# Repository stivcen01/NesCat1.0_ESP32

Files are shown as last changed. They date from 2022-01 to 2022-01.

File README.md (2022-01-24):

# NesCat1.0_ESP32
Due to increased popularity of NesCat 0.5 project, I remastered old version of NESCAT 1.0 (NCAT) project (this is deprecated version).
This is experimental version and nothing is guaranteed.



SCHEMATIC:

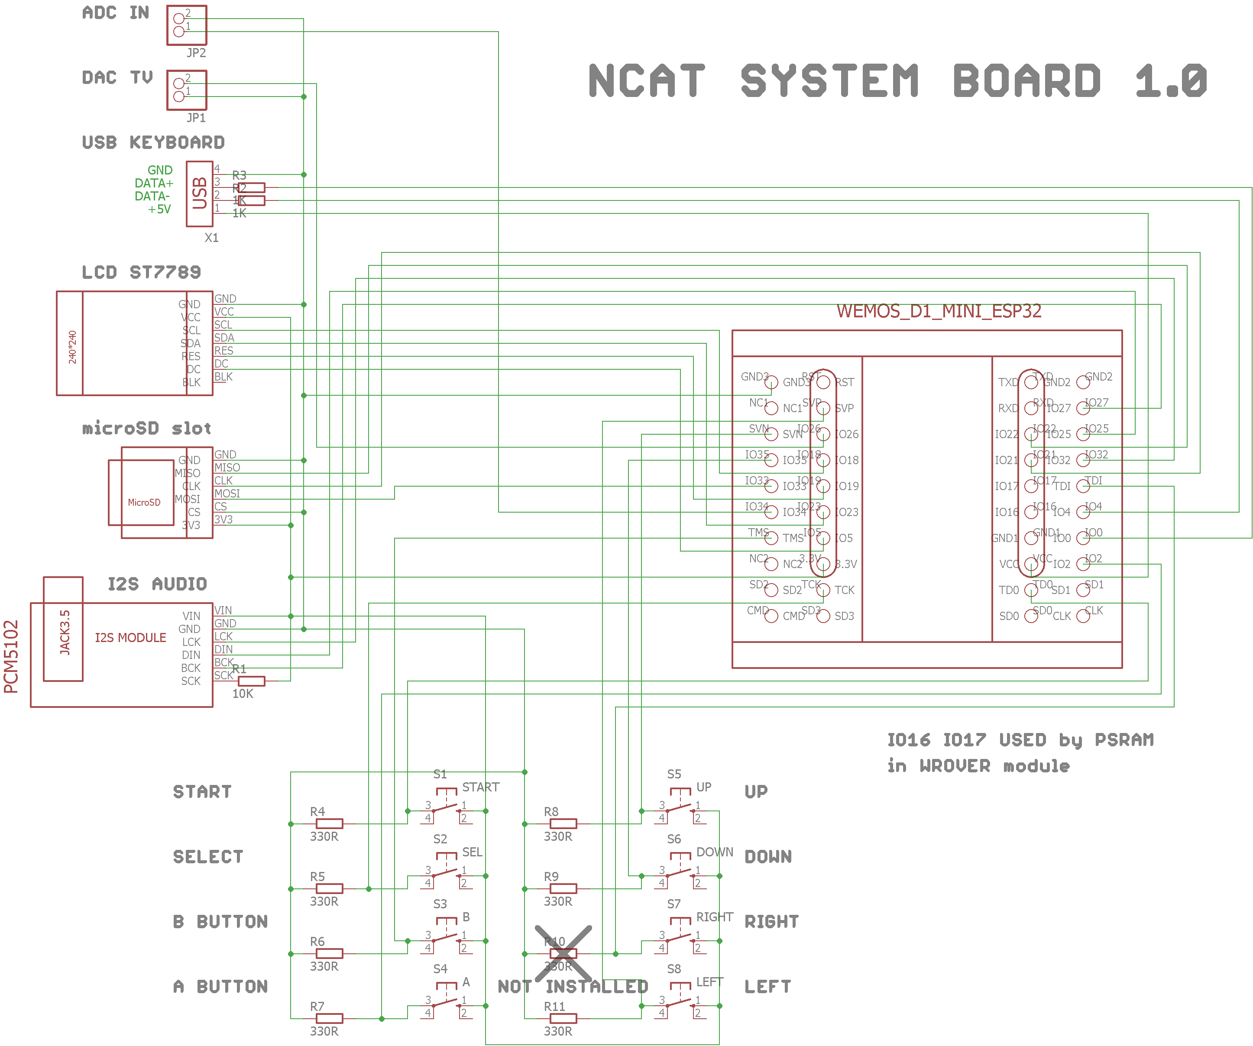
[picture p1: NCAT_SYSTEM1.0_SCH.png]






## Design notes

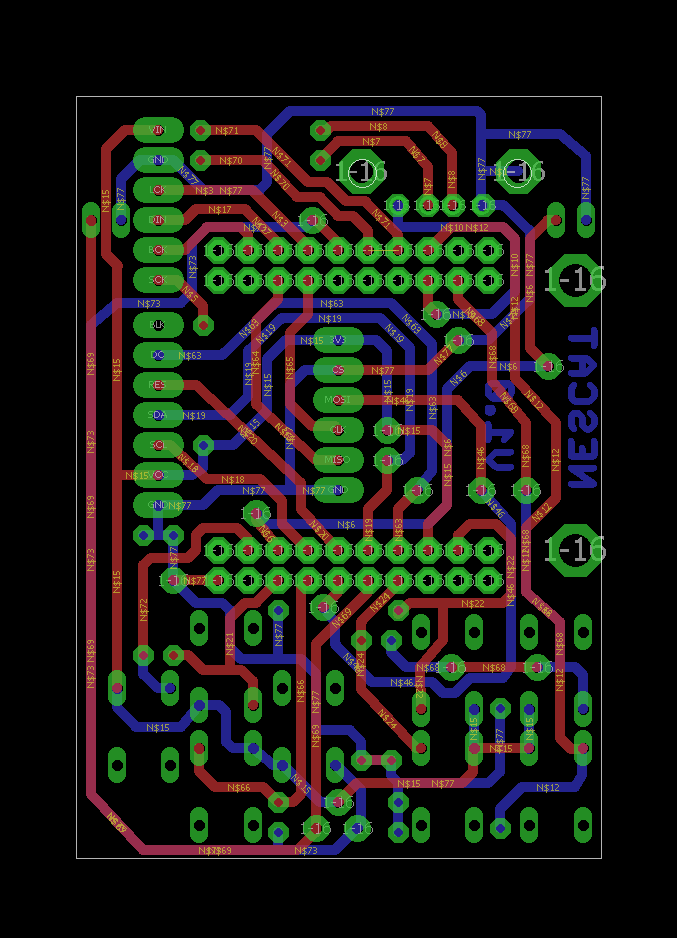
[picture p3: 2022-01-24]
HARDWARE/PCB NESCAT 1.0/NESCAT1.0_BRD2.png

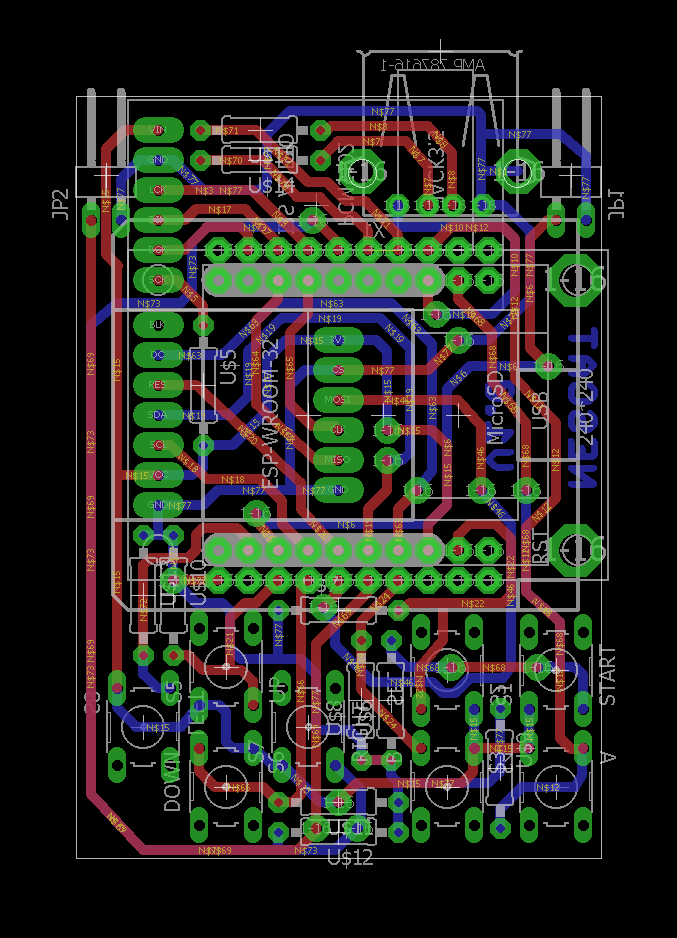
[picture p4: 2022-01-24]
HARDWARE/PCB NESCAT 1.0/NESCAT1.0_BRD.png

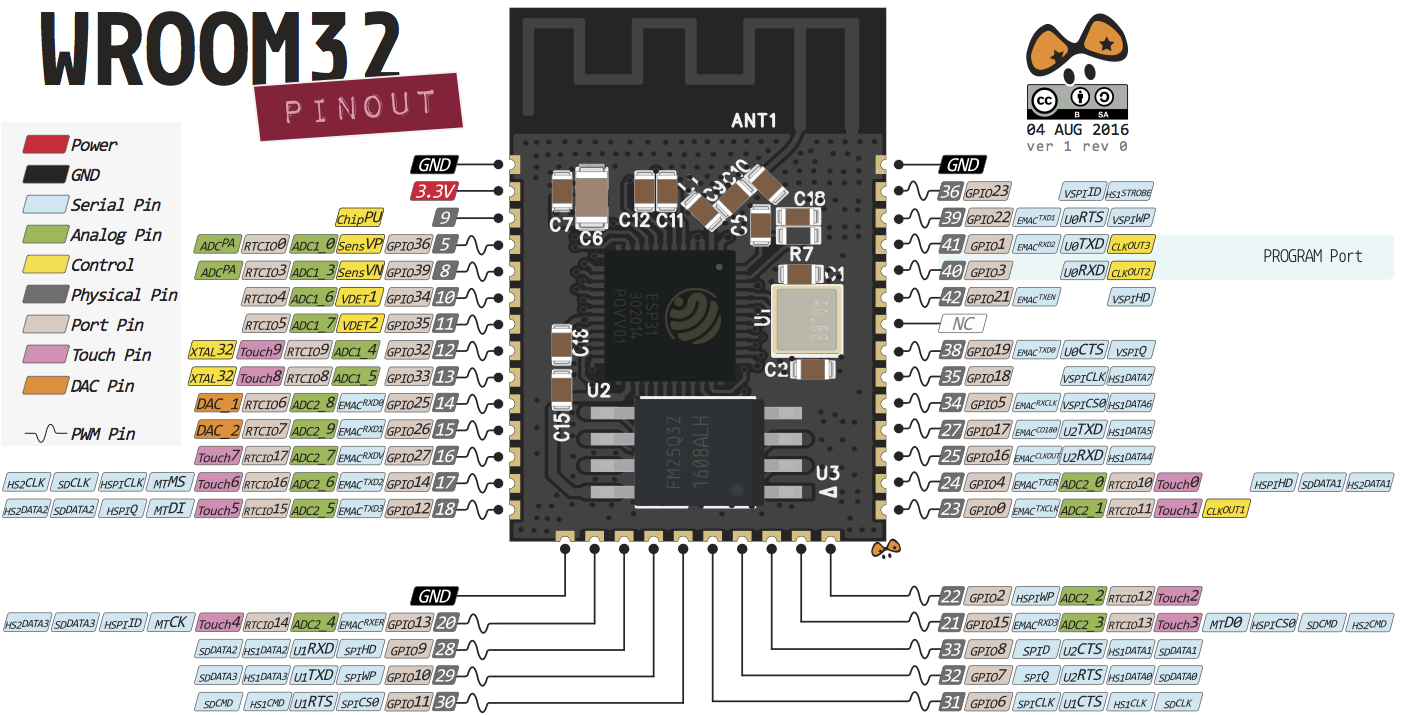
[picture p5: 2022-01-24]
RESOURCES/esp32-pinout-chip-ESP-WROOM-32.png

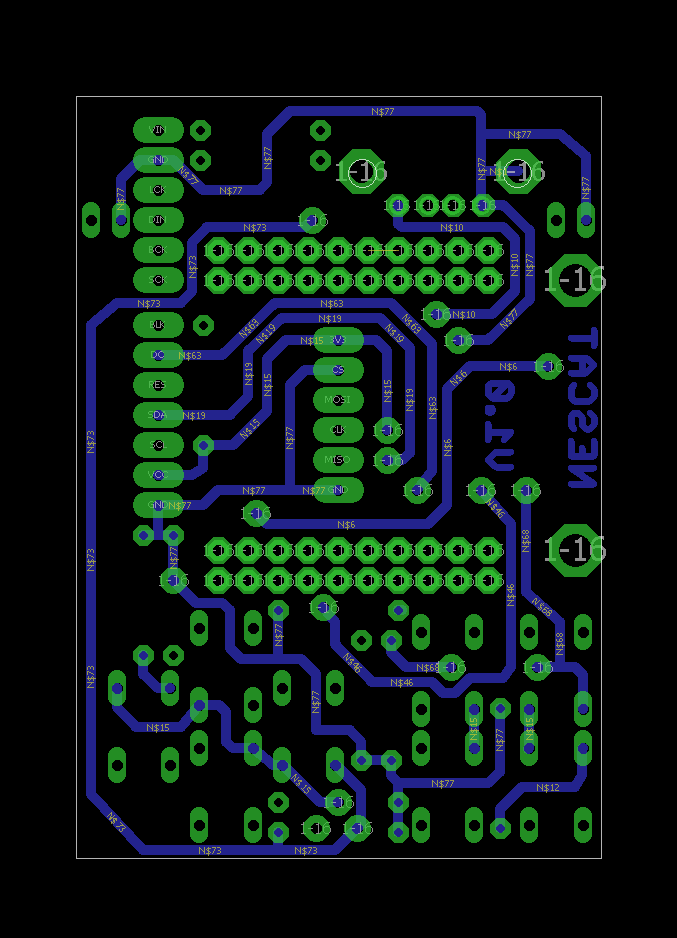
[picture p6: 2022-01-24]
HARDWARE/PCB NESCAT 1.0/NESCAT1.0_BRD_BOTTOM.png

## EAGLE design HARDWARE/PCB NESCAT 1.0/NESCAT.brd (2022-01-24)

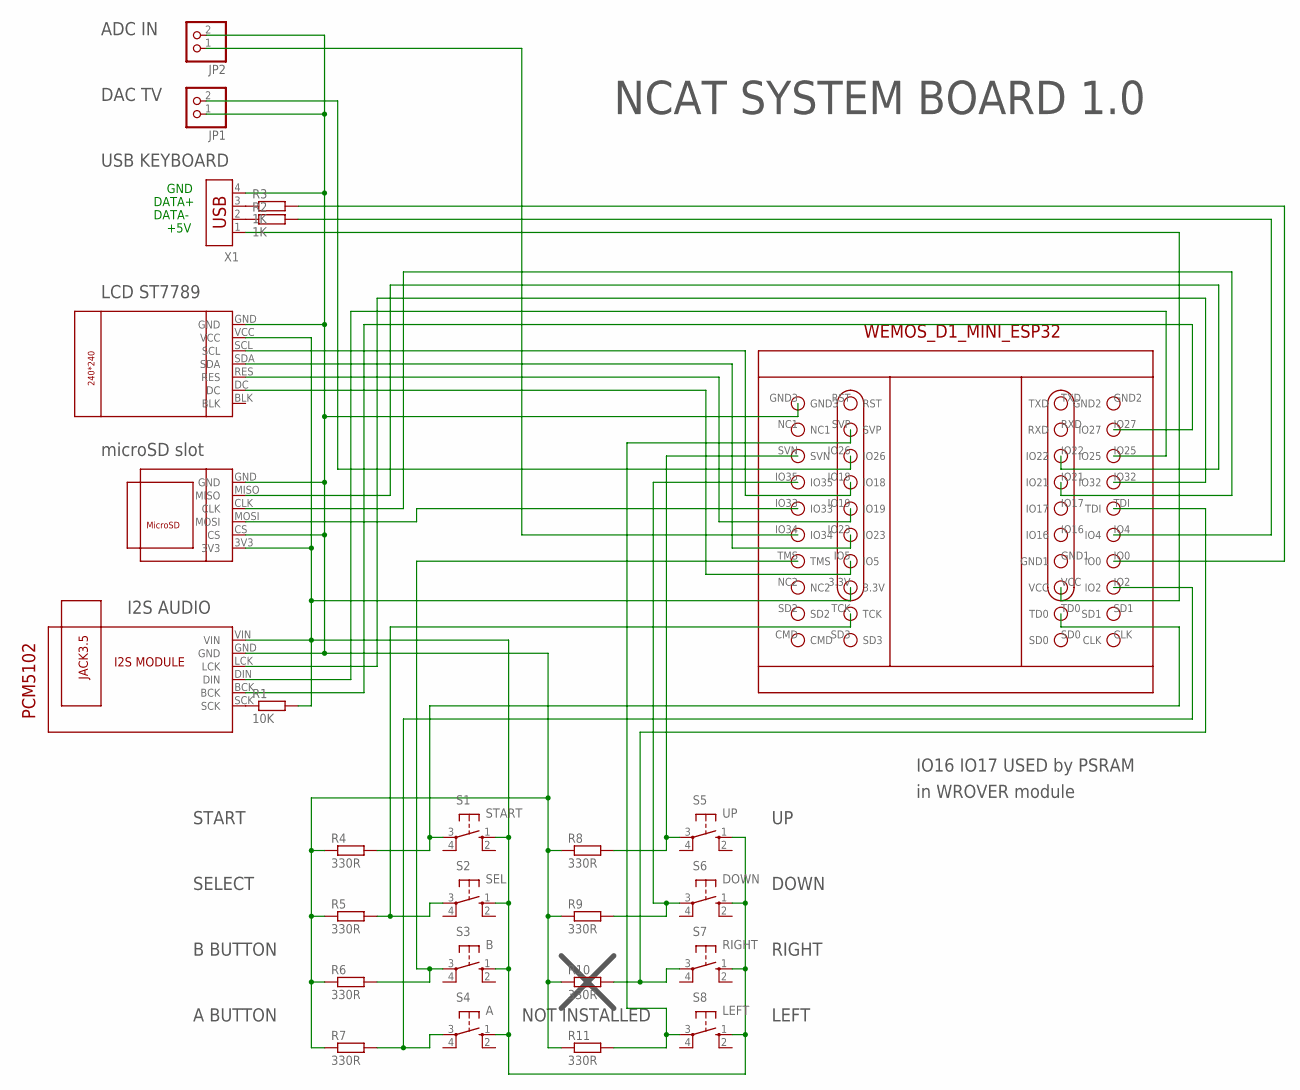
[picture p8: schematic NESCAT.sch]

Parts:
JP1, JP2: PINHD-1X2/90; 1X02/90
R1: 10K; R-0207/10H
R2, R3: 1K; R-0207/10H
R4, R5, R6, R7, R8, R9, R10, R11: 330R; R-0207/10H
S1: START; B3F-10XX
S2: SEL; B3F-10XX
S3: B; B3F-10XX
S4: A; B3F-10XX
S5: UP; B3F-10XX
S6: DOWN; B3F-10XX
S7: RIGHT; B3F-10XX
S8: LEFT; B3F-10XX
U$1: WEMOS_D1_MINI_ESP32
U$2: ST7789-1.3INCH
U$3: MICROSD-CARD-MODULE
U$4: I2S-MODULE-PCM5102A-LITE
X1: USB-787616; USB

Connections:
unnamed: U$1.IO32, U$4.LCK
unnamed: R1.1, U$4.SCK
unnamed: JP1.2, U$1.IO26
unnamed: R2.1, X1.2
unnamed: R3.1, X1.3
unnamed: U$1.VCC, X1.1
unnamed: R7.2, S4.3, U$1.IO2
unnamed: U$1.IO27, U$4.BCK
unnamed: R1.2, S1.1 (S), S2.1 (S), S3.1 (S), S4.1 (S), S5.1 (S), S6.1 (S), S7.1 (S), S8.1 (S), U$1.3.3V, U$2.VCC, U$3.3V3, U$4.VIN
unnamed: U$1.IO25, U$4.DIN
unnamed: U$1.IO18, U$2.SCL
unnamed: U$1.IO23, U$2.SDA
unnamed: U$1.IO19, U$2.RES
unnamed: R8.2, S5.3, U$1.SVN
unnamed: R5.2, S2.3, U$1.TCK
unnamed: R6.2, S3.3, U$1.TMS
unnamed: U$1.IO33, U$3.MOSI
unnamed: U$1.IO5, U$2.DC
unnamed: U$1.IO22, U$3.MISO
unnamed: U$1.IO21, U$3.CLK
unnamed: R9.2, S6.3, U$1.IO35
unnamed: R4.2, S1.3, U$1.TD0
unnamed: JP2.1, U$1.IO34
unnamed: R2.2, U$1.IO4
unnamed: R3.2, U$1.IO0
unnamed: R11.2, S8.3, U$1.SVP
unnamed: R10.2, S7.3, U$1.TDI
unnamed: JP1.1, JP2.2, R4.1, R5.1, R6.1, R7.1, R8.1, R9.1, R10.1, R11.1, U$1.GND3, U$2.GND, U$3.CS, U$3.GND, U$4.GND, X1.4

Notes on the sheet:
+5V
DATA-
DATA+
GND
ADC IN
DAC TV
USB KEYBOARD
LCD ST7789
microSD slot
I2S AUDIO
NOT INSTALLED
IO16 IO17 USED by PSRAM
in WROVER module
START
SELECT
A BUTTON
B BUTTON
DOWN
RIGHT
LEFT
NCAT SYSTEM BOARD 1.0

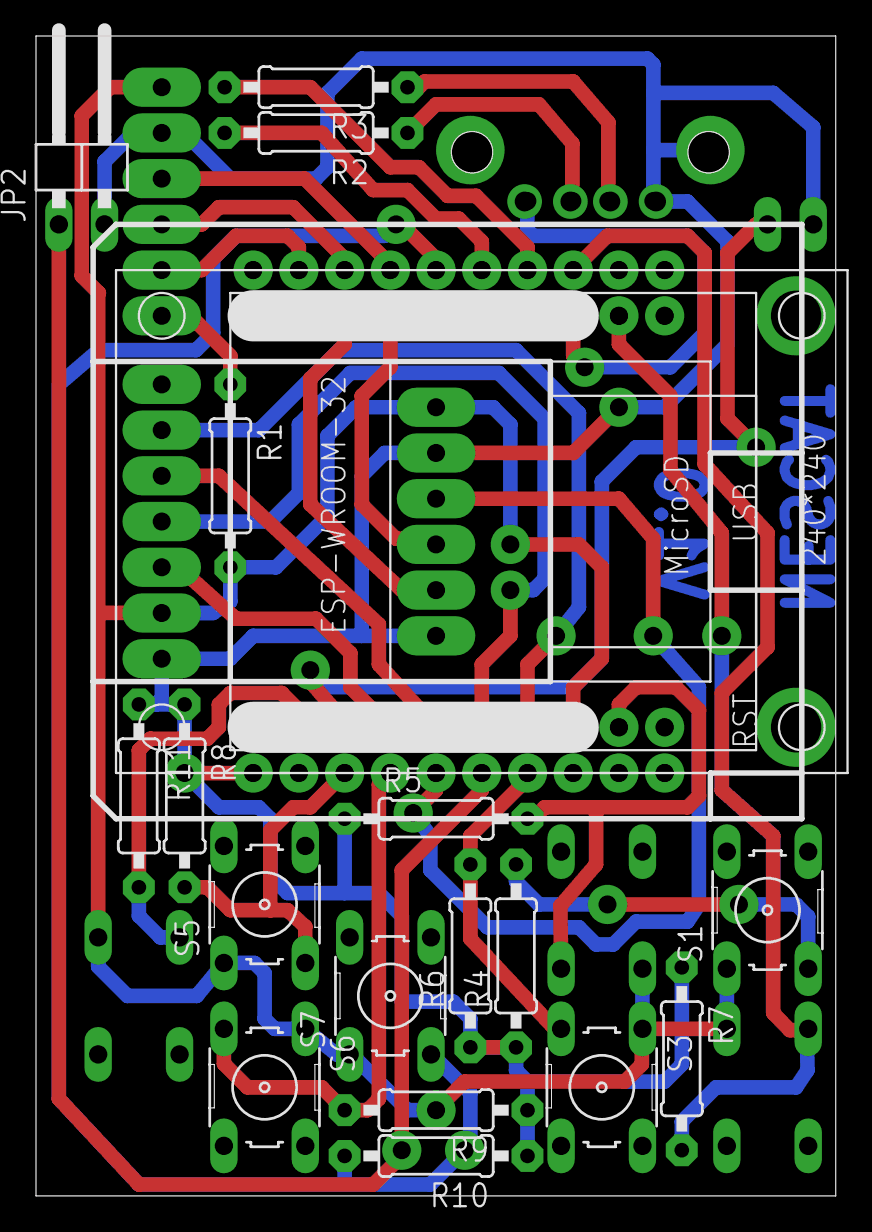
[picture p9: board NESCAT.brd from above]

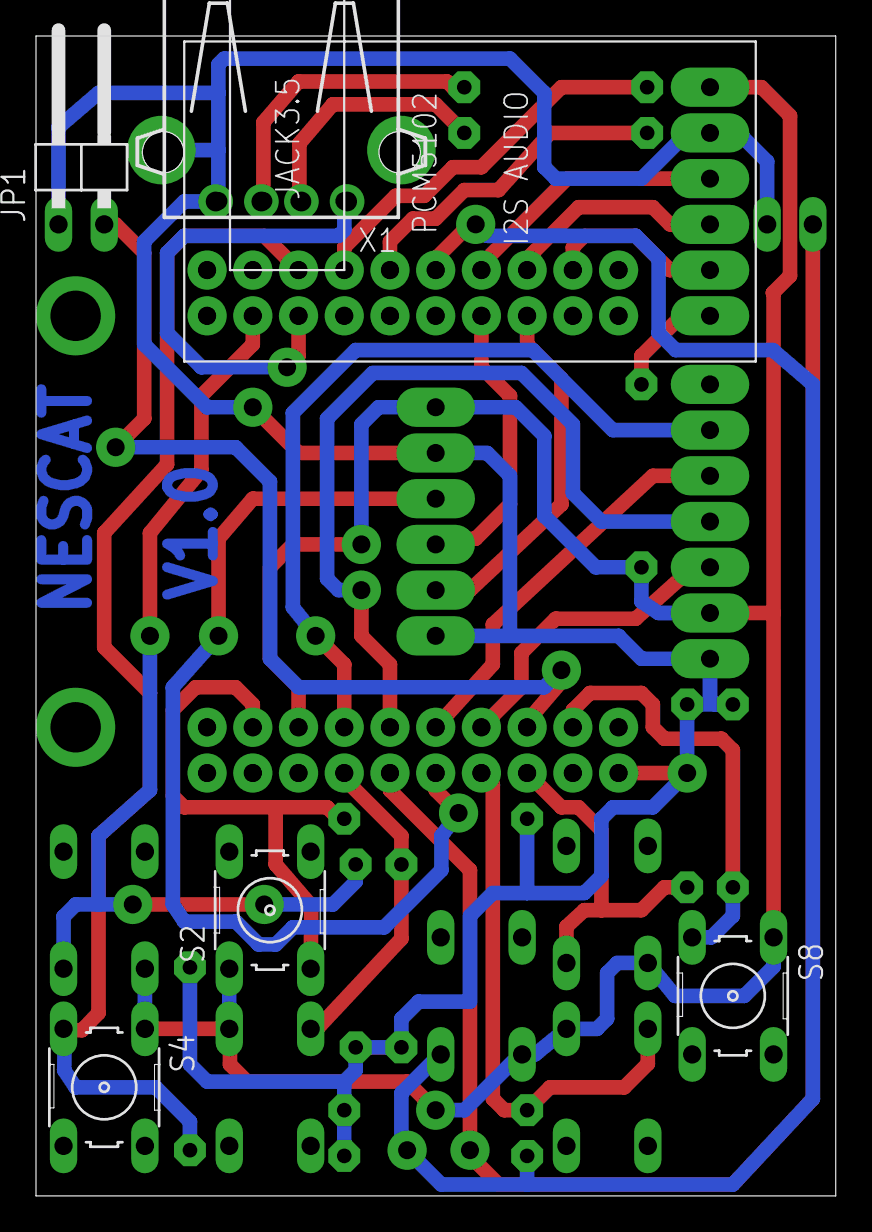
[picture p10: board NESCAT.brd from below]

Board: 2 copper layers, 44.4 x 64.4 mm, 26 parts (6 on the bottom side), 28 nets.

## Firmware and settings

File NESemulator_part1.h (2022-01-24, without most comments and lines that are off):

#define  HOST_LITTLE_ENDIAN //!!! important for Arduino
#define  ZERO_LENGTH 0
#define  UNUSED(x)   ((x) = (x))
#define DEFAULT_SAMPLERATE 24000
#define DEFAULT_FRAGSIZE 60 //max.256, default 240
#define  NES_VISIBLE_HEIGHT   240
#define  NES_SCREEN_WIDTH     256
#define  NES_SCREEN_HEIGHT    240
#define PAL
#define  NES_REFRESH_RATE     50
#define  MAX_MEM_HANDLERS     32
#define DEFAULT_WIDTH NES_SCREEN_WIDTH
#define DEFAULT_HEIGHT NES_VISIBLE_HEIGHT
#define  NES_CLOCK_DIVIDER    12  //default: 12
#define  NES_MASTER_CLOCK     (236250000 / 11)
#define  NES_SCANLINE_CYCLES  (1364.0 / NES_CLOCK_DIVIDER)
#define  NES_FIQ_PERIOD       (NES_MASTER_CLOCK / NES_CLOCK_DIVIDER / 60)
#define  NES_RAMSIZE          0x800
#define  NES6502_NUMBANKS  16
#define  NES6502_BANKSHIFT 12
#define  NES6502_BANKSIZE  (0x10000 / NES6502_NUMBANKS)
#define  NES6502_BANKMASK  (NES6502_BANKSIZE - 1)
uint8_t NES_POWER = 1;
void (*audio_callback)(void *buffer, int length) = NULL;
int pad0_readcount, pad1_readcount, ppad_readcount, ark_readcount;
void input_strobe(void) {
  pad0_readcount = 0;
  pad1_readcount = 0;
  ppad_readcount = 0;
  ark_readcount = 0;
}
uint8_t get_pad0(void) {
  uint8_t value;
  value = 0;
  if (digitalRead(PIN_A) == 1) value |= 1; //A
  if (digitalRead(PIN_B) == 1) value |= 2; //B
  if (digitalRead(PIN_SELECT) == 1) value |= 4; //SELECT
  if (digitalRead(PIN_START) == 1) value |= 8; //START
  if (digitalRead(PIN_UP) == 1) value |= 16; //UP
  if (digitalRead(PIN_DOWN) == 1) value |= 32; //DOWN
  if (digitalRead(PIN_LEFT) == 1) value |= 64; //LEFT
  if (digitalRead(PIN_RIGHT) == 1) value |= 128; //RIGHT
  if (digitalRead(PIN_SELECT) == 1 && digitalRead(PIN_START) == 1) {
    NES_POWER = 0; //EXIT
  }
  if (JOY_SHARE == 1 && JOY_OPTIONS == 1) {
    JOY_SHARE = 0;
    JOY_OPTIONS = 0;
    NES_POWER = 0;
  }
  if (JOY_SHARE == 1) value |= 8; //START
  if (JOY_OPTIONS == 1) value |= 4; //SELECT
  if (JOY_UP == 1) value |= 16; //UP
  if (JOY_DOWN == 1) value |= 32; //DOWN
  if (JOY_LEFT == 1) value |= 64; //LEFT
  if (JOY_RIGHT == 1) value |= 128; //RIGHT
  if (JOY_CROSS == 1) value |= 1; //A
  if (JOY_SQUARE == 1) value |= 2; //B
  return (((value >> pad0_readcount++) & 1));
}
TimerHandle_t timer_1;
IRAM_ATTR int osd_installtimer_1(int frequency, void *func, int funcsize, void *counter, int countersize)
{
  if (DEBUG) Serial.print("Timer install, freq=");
  if (DEBUG) Serial.println(frequency);
  delay(1000);
  timer_1 = xTimerCreate("nes_hid", configTICK_RATE_HZ / frequency, pdTRUE, NULL, (TimerCallbackFunction_t)func);
  xTimerStart(timer_1, 0);
  return 0;
}
typedef struct sndinfo_s
{
  int sample_rate;
  int bps;
} sndinfo_t;
#if SOUND_ENABLED
intr_handle_t i2s_interrupt;
i2s_pin_config_t pin_config = {
  .bck_io_num = I2S_BCK_IO,
  .ws_io_num = I2S_WS_IO,
  .data_out_num = I2S_DO_IO,
  .data_in_num = I2S_DI_IO                                               //Not used
};
i2s_config_t audio_cfg = {
  .mode = static_cast<i2s_mode_t>(I2S_MODE_MASTER | I2S_MODE_TX ),
  .sample_rate = DEFAULT_SAMPLERATE,
  .bits_per_sample = I2S_BITS_PER_SAMPLE_16BIT,
  .channel_format = I2S_CHANNEL_FMT_RIGHT_LEFT,
  .communication_format = static_cast<i2s_comm_format_t>(I2S_COMM_FORMAT_PCM | I2S_COMM_FORMAT_I2S | I2S_COMM_FORMAT_I2S_MSB),
  .intr_alloc_flags = ESP_INTR_FLAG_LEVEL1  ,
  .dma_buf_count = 6,
  .dma_buf_len = 4 * DEFAULT_FRAGSIZE,
  .use_apll = false
};
#endif
int init_sound(void)
{
#if SOUND_ENABLED
  i2s_driver_install(I2S_NUM_1, &audio_cfg, 0, NULL);
  i2s_set_pin(I2S_NUM_1, &pin_config);
  i2s_set_sample_rates(I2S_NUM_1, DEFAULT_SAMPLERATE);
#endif
  audio_callback = NULL;
  return 0;
}
void osd_setsound(void (*playfunc)(void *buffer, int length))
{
  audio_callback = playfunc;
}
void osd_stopsound(void)
{
  audio_callback = NULL;
}
void osd_getsoundinfo(sndinfo_t *info);
void osd_getsoundinfo(sndinfo_t *info)
{
  info->sample_rate = DEFAULT_SAMPLERATE;
  info->bps = 16;
}
#if SOUND_ENABLED
QueueHandle_t queue;
uint16_t audio_frame[2 * DEFAULT_FRAGSIZE];
#endif
void do_audio_frame()
{
#if SOUND_ENABLED
  int left = DEFAULT_SAMPLERATE / NES_REFRESH_RATE;
  while (left)
  {
    int n = DEFAULT_FRAGSIZE;
    if (n > left)
      n = left;
    audio_callback(audio_frame, n); //get more data
    for (int i = n - 1; i >= 0; i--)
    {
      uint16_t a = (audio_frame[i] >> 0);
      audio_frame[i * 2 + 1] = 0x8000 + a;
      audio_frame[i * 2] = 0x8000 - a;
    }
    size_t i2s_bytes_write;
    i2s_write(I2S_NUM_1, (const char *)audio_frame, 4 * n, &i2s_bytes_write, portMAX_DELAY);
    left -= i2s_bytes_write / 4;
  }
#endif
}
volatile int time_ticks = 0;
IRAM_ATTR static void timer_isr(void)
{
  if (SOUND_ENABLED)
    if (audio_callback && NES_POWER == 1) do_audio_frame();
  time_ticks++;
}
IRAM_ATTR static void timer_isr_end(void) {}
IRAM_ATTR int install_timer(int hertz) {
  return osd_installtimer_1(hertz, (void *) timer_isr, (int) timer_isr_end - (int) timer_isr, (void *) &time_ticks, sizeof(time_ticks));
}
char* NESEXPLORE(char* PATH) {
  uint8_t num = 0;
  uint8_t loadedFileNames = 0;
  for (uint16_t tmp = 0; tmp < MAXFILES; tmp++) memset (filename[tmp], 0, sizeof(filename[tmp]));
  fileext[0] = 0;
  fileext[1] = 0;
  fileext[2] = 0;
  fileext[3] = 0;
  num = 0;
  loadedFileNames = 0;
  if (!dirFile.open(PATH, O_READ)) {
    while (1) {};
  }
  while (num < MAXFILES && file.openNext(&dirFile, O_READ)) {
    if (!file.isHidden()) {
      for (uint8_t i = strlen(filename[num]); i > 3; i--) filename[num][i] = 0;
      file.getName(filename[num], MAXFILENAME_LENGTH);
      if (file.isSubDir()) {
        sprintf(filename[num], "%s/", filename[num]);
        num++;
      } else {
        for (uint8_t i = strlen(filename[num]); i > 3; i--) {
          if (filename[num][i] != 0) {
            fileext[3] = '\0';
            fileext[2] = filename[num][i];
            fileext[1] = filename[num][i - 1];
            fileext[0] = filename[num][i - 2];
            break;
          }
        }
      }
      if (DEBUG) {
      }
      if ((fileext[0] == 'N' || fileext[0] == 'n')
          && (fileext[1] == 'E' || fileext[1] == 'e')
          && (fileext[2] == 'S' || fileext[2] == 's')) {
        num++;
      }
    }
    loadedFileNames = num;
    file.close();
  }
  dirFile.close();
  if (DEBUG) {
    Serial.println("--------------------------------------");
    Serial.print("Count of loaded File Names:");
    Serial.println(loadedFileNames);
  }
  sortStrings(filename, loadedFileNames);
  uint8_t CURSOR = 0;
  uint8_t PAGE = 0;
  bool NamesDisplayed = false;
  while (1) {
    PAGE = CURSOR / FILESPERPAGE;
    if (!NamesDisplayed) {
      screenmemory_fillscreen(63); //black color
      set_font_XY(16, 24 );
      draw_string(PATH);
      for (num = PAGE * FILESPERPAGE; num < ((PAGE + 1)*FILESPERPAGE) && num < loadedFileNames; num++) {
        set_font_XY(40, 48 + 20 * (num % FILESPERPAGE));
        if (filename[num][strlen(filename[num]) - 1] == '/') draw_string(filename[num], 23);
        else draw_string(filename[num], 48);
        delay(1);
      }
      NamesDisplayed = true;
    }
    set_font_XY(16, 48 + (20 * (CURSOR % FILESPERPAGE)));
    draw_string("->", 48);
    delay(200);
    while (JOY_CROSS == 0 && JOY_SQUARE == 0 && JOY_OPTIONS == 0 && JOY_SHARE == 0 && JOY_UP == 0 && JOY_DOWN == 0 && JOY_LEFT == 0 && JOY_RIGHT == 0) {
      if (digitalRead(PIN_A) == 1) {
        JOY_CROSS = 1;  //A
        delay(25);
      }
      if (digitalRead(PIN_B) == 1) {
        JOY_SQUARE = 1;   //B
        delay(25);
      }
      if (digitalRead(PIN_SELECT) == 1) {
        JOY_OPTIONS = 1;   //SELECT
        delay(25);
      }
      if (digitalRead(PIN_START) == 1) {
        JOY_SHARE = 1;   //START
        delay(25);
      }
      if (digitalRead(PIN_UP) == 1) {
        JOY_UP = 1;
        delay(25);
      }
      if (digitalRead(PIN_DOWN) == 1) {
        JOY_DOWN = 1;   //DOWN
        delay(25);
      }
      if (digitalRead(PIN_LEFT) == 1) {
        JOY_LEFT = 1;   //LEFT
        delay(25);
      }
      if (digitalRead(PIN_RIGHT) == 1) {
        JOY_RIGHT = 1;   //RIGHT
        delay(25);
      }
    }
    set_font_XY(16, 48 + (20 * (CURSOR % FILESPERPAGE)));
    draw_string("  ", 48);
    if (JOY_SHARE == 1 && JOY_OPTIONS == 1) {
      JOY_SHARE = 0;
      JOY_OPTIONS = 0;
      EXIT = true;
      NES_POWER = 0;
      return MAINPATH;
    }
    if (JOY_UP == 1 ) {
      if (CURSOR % FILESPERPAGE == 0) NamesDisplayed = false; //changed page
      if (CURSOR == 0 && loadedFileNames > 0) CURSOR = loadedFileNames - 1;
      else if (CURSOR > 0 && loadedFileNames > 0) CURSOR--;
      JOY_UP = 0;
    }
    if (JOY_DOWN == 1 ) {
      if (CURSOR % FILESPERPAGE == FILESPERPAGE - 1 || CURSOR == loadedFileNames - 1) NamesDisplayed = false; //changed page
      if (CURSOR == loadedFileNames - 1 && loadedFileNames > 0) CURSOR = 0;
      else if (CURSOR < loadedFileNames - 1 && loadedFileNames > 0) CURSOR++;
      JOY_DOWN = 0;
    }
    if (JOY_LEFT == 1) {
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

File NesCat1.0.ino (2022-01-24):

//                          ▄▀▀█▄                ▄██▀▀▄       
//                         ▐█░░ ▀██▄          ▄███▀░░░█       
//                         ▐█░░░░░▀█████████████▀▒░░░░█       
//                 ▄▄████████░░▒▒▒▒░██████████████░▒░░█       
//             ▄█████████████▄▒▒▒▒▒▄████████████████░▐        
//           ▄████████████████▄▄▄█████████  ▀████████▌        
//          ▐█████████▀▀▀▀▀█████████████▀    ▀███████▌        
//         ▐█▀███▀▀▄       ▐██████████▀        ▀█████▌        
//         ▓▌               ░████▀▀▀   ▀▄    ▄▀   ▀██         
//        ▄██              ▐ ▀▌                    ▄▀         
//       ▓███▒             ▐  ▀▓▄▒         ▄    ▒▄▀▀          
//       █████▒▒         ▒▒▌             ▀▀▒▀▀▀ ▀█            
//       ▓████████████████████▒▒         ▄ ▄▄ ▒▄▒▄█▄▄         
//     ▄▄███████████████████████████████████▀██████████▄▄     
//  ▄█▀▒▒▀▒▒▒▀█▓▀▒█▓▒▒▓█▀▒▒▀█▄▒▒▒▒█▄████▓▓▓███▒███▓▓████▓██   
// ▐█▒▒▒▒▒▒▒▀▒▄▒▀▒▄▄▒▒▀█▄▒▒▒▄█▒▓▄█████▓▓███████▓▓▒▒███▀▒▓▒▒██▄
//  ▀▀█▄▒▒▒▒▄▄▒▒▒▄▒▒█▄▒▒▒▒▀▒▒▒▒▒▄███▄██▀▒██▒██▒▓▓▓▓▓▓▓▓▒▄█▀▀  
//      ▀▀█▄▒▒██▒▒█████████▒▒▒▒██▀▄██▒▒▄▓▓▓▓▓▒▒▓▓▓▓▒▄█▀▀      
//          ▀▀████▓████▓████▒▒▒▒▒▒▒▄▒▀▄█▓██▒▒▓▓▒▄█▀▀          
//              ▀▀███████▀▀▀▒▒▄▄▀▀▒▄▓█▓▒▒▓█▒██▀▀              
//                  ▀███▀████▄▒▓▓█▌▒▒▓█▒██▀▀                  
//                      ▀██▒▒▒▒▓▓▓▓▒███▀                      
//                          ▀▀▀▀▀▀▀▀                          

//********************************************************************************
//*                                                                              *
//*   NCAT SYSTEM 1.0 by Nathalis                                                *
//*                                                                              *
//*   Includes: 1. NES EMULATOR, 2. MP3 player, 3. Oscilloscope 1MHz             *
//*                                                                              *
//*   Requirements: ESP32 WEMOS D1 MINI, SD7789 LCD, MICROSD CARD slot,          *
//*   PCM5102 I2S AUDIO MODULE, OTHER PARTS...                                   *
//*                                                                              *
//*   Only for personal & educational use!                                       *
//*   (GPL-3.0 License)                                                          *
//*                                                                              *
//********************************************************************************
//*                                                                              *
//*   features:                                                                  *
//*   - ESP32-WROVER PSRAM module support                                        *
//*   - MicroSD card support                                                     *
//*   - 240*240 1.3" LCD ST7789 display                                          *
//*   - Composite TV OUT Video PAL                                               *
//*   - I2S AUDIO support PCM5102 module                                         *
//*   - PS2 (USB) KEYBOARD support (wireless not work)                           *
//*   - huge NES ROMs up to 512kB (read from FLASH)                              *
//*   - PS4 DualShock BlueTooth Gamepad (experimental)                           *
//*                                                                              *
//********************************************************************************

// Enable modified included libraries in "/src/" folder but if you have libraries conflict try:
// ... in other case you need copy modified from "/LIBRARIES/" to "/Arduino/libraries/" folder 
// and disable this option in this case (but you must delete modified included libraries from "/src/" folder):

#define INCLUDED_LIBRARIES true //better enable this feature!                           

#define LCD_ENABLED true
#define COMPOSITE_VIDEO_ENABLED true  //Do not disable! it also disable ADC.
#define KEYBOARD_ENABLED true
#define SOUND_ENABLED true
#define BLUETOOTH_ENABLED false //experimental.

#define DEBUG true       //Serial debugging enable.
#define DEBUGEXTRA false //Extra Serial debugging enable.

//********************************************************************************

//KEY BUTTONS PINS:
#define PIN_UP     39  //SVN
#define PIN_DOWN   35  //IO35
#define PIN_LEFT   36  //SVP
#define PIN_RIGHT  12  //TDI => Do not install 330R resistor!!!
#define PIN_A      2   //IO2
#define PIN_B      14  //TMS
#define PIN_START  15  //TDO
#define PIN_SELECT 13  //TCK

///!!! do not forget 1KOHM resistors
#define KEYBOARD_DATA 4  /// ---[ 1K ]--- // -D
#define KEYBOARD_CLK 0   /// ---[ 1K ]--- // +D

//COMPOSITE_VIDEO: - //DAC_GPIO25_CHANNEL or DAC_GPIO26_CHANNEL
#define VIDEO_OUT (DAC_GPIO26_CHANNEL)

//AUDIO_i2S:
#define I2S_BCK_IO (GPIO_NUM_27) //BCK
#define I2S_WS_IO  (GPIO_NUM_32) //LCK
#define I2S_DO_IO  (GPIO_NUM_25) //DIN
#define I2S_DI_IO  (-1)

//LCD_ST7789:
#define TFT_CS   -1  // define chip select pin
#define TFT_DC    5  // define data/command pin
#define TFT_RST  19
#define TFT_MOSI 23  // Data out (SDA) //better not change
#define TFT_SCLK 18  // Clock out (SCL) //better not change

//micro_SD_Card: //GPIO16 and GPIO17 can not use on WROVER
#define SOFTSD_MOSI_PIN (GPIO_NUM_33)
#define SOFTSD_MISO_PIN (GPIO_NUM_22)
#define SOFTSD_SCK_PIN (GPIO_NUM_21)
#define SD_CS_PIN -1  //

//Oscilloscope INPUT:
#define ADC_CHANNEL   ADC1_CHANNEL_6 // GPIO34

// player Digital I/O used
#define SD_CS          -1
#define SPI_MOSI      SOFTSD_MOSI_PIN
#define SPI_MISO      SOFTSD_MISO_PIN
#define SPI_SCK       SOFTSD_SCK_PIN
#define I2S_DOUT      I2S_DO_IO
#define I2S_BCLK      I2S_BCK_IO
#define I2S_LRC       I2S_WS_IO
//********************************************************************************
//MAIN LIBRARIES:

#include <esp_task_wdt.h>
#include "esp_types.h"
#include "esp_heap_caps.h"
#include "esp_attr.h"
#include "esp_intr_alloc.h"
#include "esp_err.h"
#include "soc/gpio_reg.h"
#include "soc/rtc.h"
#include "soc/soc.h"
#include "soc/i2s_struct.h"
#include "soc/i2s_reg.h"
#include "soc/ledc_struct.h"
#include "soc/rtc_io_reg.h"
#include "soc/io_mux_reg.h"
#include "rom/gpio.h"
#include "rom/lldesc.h"
#include "driver/periph_ctrl.h"
#include "driver/dac.h"
#include "driver/gpio.h"
#if SOUND_ENABLED
#include "driver/i2s.h"
#endif

//LIBRARIES:
#include "Arduino.h"
//AUDIO_i2S:

//********************************************************************************
#if INCLUDED_LIBRARIES

//MODIFIED INCLUDED_LIBRARIES in "/src/" folder

//LCD_ST7789:
#include <SPI.h>
#include "src/Adafruit-GFX-Library/Adafruit_GFX.h"    // Core graphics library
#include "src/Adafruit-ST7735-Library/Adafruit_ST7789.h"    // Core graphics library

//micro_SD_Card:
#include "src/sdfat-beta/src/SdFat.h" // Use SDFAT-beta...

//AUDIO_i2S:
#if SOUND_ENABLED
#include "driver/i2s.h"
#endif

//player LIBs
#include "src/ESP32-audioI2S/src/Audio.h" // Use SDFAT-beta...

//--------------------------------------------------------------------------------
///#include "arduinoFFT.h" // Standard Arduino FFT library
#include "src/arduinoFFT/src/arduinoFFT.h" // Standard Arduino FFT library

//********************************************************************************
#else
//********************************************************************************

//!!! or use MODIFIED LIBRARIES in "Arduino/libraries/" folder (need copy from /LIBRARIES/)

//LCD_ST7789:
#include <SPI.h>
#include <Adafruit_GFX.h>    // Core graphics library
#include <Adafruit_ST7789.h> // Hardware-specific library for ST7789

//micro_SD_Card:
#include <SdFat.h> // Use SDFAT-beta...

//player LIBs
#include "Audio.h" //ESP32-audioI2S

#include "arduinoFFT.h" // Standard Arduino FFT library
//********************************************************************************
#endif



// https://github.com/kosme/arduinoFFT, in IDE, Sketch, Include Library, Manage Library, then search for FFT
arduinoFFT FFT = arduinoFFT();

//********************************************************************************
//SETUP:

//USE SDFAT BETA!
///SdFatSoftSpi<SOFTSD_MISO_PIN, SOFTSD_MOSI_PIN, SOFTSD_SCK_PIN> SD;
SoftSpiDriver<SOFTSD_MISO_PIN, SOFTSD_MOSI_PIN, SOFTSD_SCK_PIN> softSpi;
#define SD_CONFIG SdSpiConfig(-1, DEDICATED_SPI, SD_SCK_MHZ(0), &softSpi)
SdFat SD;
File fp;

//LCD_ST7789
#define ST7789_DRIVER     // Configure all registers
#define TFT_WIDTH  240
#define TFT_HEIGHT 240
#define LOAD_GLCD   // Font 1. Original Adafruit 8 pixel font needs ~1820 bytes in FLASH
#define LOAD_FONT2  // Font 2. Small 16 pixel high font, needs ~3534 bytes in FLASH, 96 characters
#define LOAD_FONT4  // Font 4. Medium 26 pixel high font, needs ~5848 bytes in FLASH, 96 characters
Adafruit_ST7789 tft = Adafruit_ST7789(TFT_CS, TFT_DC, TFT_RST);

//********************************************************************************
//VARIABLES:

//Allocated MEMORY variables:
uint8_t* SCREENMEMORY[256 + 1];  //256*256 bytes + 256 offset
uint16_t SCREENBUFFER[256];  //512 bytes

uint32_t PSRAMSIZE = 0;
uint8_t* PSRAM;

//--------------------------------------------------------------------------------
//SPI FLASH MEMORY ACCESS:
#include "esp_spi_flash.h"

#define SPI_FLASH_ADDRESS 0x00300000 //0x00300000 working (empty flash area)
#define SPI_FLASH_SECTOR_SIZE 0x1000 //4kB = better not change

uint32_t FILE_ROM_SIZE = 0;
uint32_t FLASH_ROM_SIZE = 0;

//constant data pointer for direct access
const void *ROM;

spi_flash_mmap_handle_t handle1;

uint8_t flashdata[4096] = {0}; //4kB buffer

//--------------------------------------------------------------------------------
//DRAM MEMORY ACCESS:
//--------------------------------------------------------------------------------

char* ROMFILENAME; //NES load File name
unsigned char *rom = 0; //Actual ROM pointer

//********************************************************************************


//--------------------------------------------------------------------------------
//NES PALETTES 32bit & 16bit:

const uint32_t nes_32bit[64] = { //4colors Green-Yellow-Red-Blue
  0x2D253469, 0x000000D9, 0x000000A1, 0x0F111CA1, 0x001F3F70, 0x0024491C, 0x06264900, 0x061F3B00,
  0x12162300, 0x2D0B0000, 0x27090000, 0x21080000, 0x1806004D, 0x14141414, 0x14141414, 0x14141414,
  0x453950A1, 0x2D0B00D9, 0x210800D9, 0x181C2DD9, 0x002F5EAF, 0x0031624D, 0x153B6C00, 0x2139620E,
  0x2D304900, 0x45110000, 0x3F0F0000, 0x3F0F0038, 0x330C0077, 0x14141414, 0x14141414, 0x14141414,
  0x5D4D6CD9, 0x451D18D9, 0x33232DD9, 0x2D2C42D9, 0x2D416CD9, 0x213E6C85, 0x2D416C4D, 0x3C456C38,
  0x45476C00, 0x5D3F5015, 0x51272646, 0x5D2A2685, 0x571500BD, 0x2D253469, 0x14141414, 0x14141414,
  0x5D4D6CD9, 0x543846D9, 0x453950D9, 0x45405ED9, 0x45476CD9, 0x3C456CA8, 0x4E48699A, 0x544B6C93,
  0x514A6C69, 0x5D465E69, 0x5D3F50A1, 0x5D3F50BD, 0x5D1700D9, 0x514A6CD9, 0x14141414, 0x14141414,
};

const uint16_t nes_16bit[64] = {
  0x7BEF, 0x001F, 0x0017, 0x4157, 0x9010, 0xA804, 0xA880, 0x88A0,
  0x5180, 0x03C0, 0x0340, 0x02C0, 0x020B, 0x0000, 0x0000, 0x0000,
  0xBDF7, 0x03DF, 0x02DF, 0x6A3F, 0xD819, 0xE00B, 0xF9C0, 0xE2E2,
  0xABE0, 0x05C0, 0x0540, 0x0548, 0x0451, 0x0000, 0x0000, 0x0000,
  0xFFDF, 0x3DFF, 0x6C5F, 0x9BDF, 0xFBDF, 0xFAD3, 0xFBCB, 0xFD08,
  0xFDC0, 0xBFC3, 0x5ECA, 0x5FD3, 0x075B, 0x7BCF, 0x0000, 0x0000,
  0xFFFF, 0xA73F, 0xBDDF, 0xDDDF, 0xFDDF, 0xFD38, 0xF696, 0xFF15,
  0xFECF, 0xDFCF, 0xBFD7, 0xBFDB, 0x07FF, 0xFEDF, 0x0000, 0x0000,
};
//--------------------------------------------------------------------------------
//for player...
bool PLAYING = false;
bool PAUSED = false;
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
void loop() {
  
  screenmemory_fillscreen(63); //black color

  EXIT = 0;
  switch (MENU()) {
    case 1:

      MEMORY_STATUS();
      //--------------------------------------------------------------------------------
      Serial.println("Starting NES EMULATOR appliication.");
      screenmemory_fillscreen(63); //black color

      init_sound(); //START AUDIO

      Serial.println("NES_POWER: ##################");

      if (NULL == NESmachine) NESmachine = nes_create();
      if (NULL == NESmachine) {
        if (DEBUG) Serial.println("Failed to create NES instance.");
        if (DEBUG) tft.println("Failed to create NES instance.");
        while (1) {} //FREEZE
      }

      sprintf(MAINPATH, "/NES/"); ///must be malloc(256);

      for (uint16_t tmp = 0; tmp < MAXFILES; tmp++) filename[tmp] = (char*)calloc(MAXFILENAME_LENGTH, sizeof(char));

      NESBrowse(MAINPATH);
      delay(300);

      for (uint16_t tmp = 0; tmp < MAXFILES; tmp++) free(filename[tmp]);

      if (EXIT) {
        return; //return from NESBrowse();
      }

      screenmemory_fillscreen(63); //black color

      if (DEBUG) Serial.print("SELECTED NES: ");
      if (DEBUG) Serial.println(MAINPATH);

      romdata = (unsigned char *)getromdata(MAINPATH);

      if (DEBUG) Serial.println("Inserting cartridge.");
      if (DEBUG) tft.println("Inserting cartridge.");

//--------------------------------------------------------------------------------

      if (NULL == rominfo) rominfo = (rominfo_t*)malloc(sizeof(rominfo_t));
      if (NULL == rominfo) goto rom_load_fail;

      memset(rominfo, 0, sizeof(rominfo_t));

      // Get the header and stick it into rominfo struct
      if (rom_getheader(&romdata, rominfo)) goto rom_load_fail;

      // Make sure we really support the mapper
      if (false == mmc_peek(rominfo->mapper_number)) {
        if (DEBUG) {
          Serial.print("Mapper not yet implemented:");
          Serial.println(rominfo->mapper_number);
          tft.print("Mapper not yet implemented:");
          tft.println(rominfo->mapper_number);
        }
        goto rom_load_fail;
      }

      // iNES format doesn't tell us if we need SRAM, so we have to always allocate it -- bleh!* UNIF, TAKE ME AWAY!  AAAAAAAAAA!!!
      if (rom_allocsram(rominfo)) goto rom_load_fail; ///NEED FOR example: SMB2-LostLevels 
      rom_loadtrainer(&romdata, rominfo);
      if (rom_loadrom(&romdata, rominfo)) goto rom_load_fail;

      NESmachine->rominfo = rominfo;

      goto rom_load_success;

rom_load_fail:
      if (DEBUG) {
        Serial.println("ROMLOAD FAIL.");
        tft.println("ROMLOAD FAIL.");
      }
      while (1) {} //FREEZE

rom_load_success:

//................................................................................

      if (DEBUG) {
        Serial.println("ROMLOAD SUCCESS.");
        tft.println("ROMLOAD SUCCESS.");
        Serial.println("Inserting Cartridge...");
        tft.println("Inserting Cartridge...");
      }

      // map cart's SRAM to CPU $6000-$7FFF
      if (NESmachine->rominfo->sram) {
        NESmachine->cpu->mem_page[6] = NESmachine->rominfo->sram;
        NESmachine->cpu->mem_page[7] = NESmachine->rominfo->sram + 0x1000;
      }
      
      // mapper
      NESmachine->mmc = mmc_create(NESmachine->rominfo);
      if (NULL == NESmachine->mmc) goto inscart_fail;

      // if there's VRAM, let the PPU know
      if (NULL != NESmachine->rominfo->vram) NESmachine->ppu->vram_present = true;
      if (SOUND_ENABLED) apu_setext(NESmachine->apu, NESmachine->mmc->intf->sound_ext);
      if (SOUND_ENABLED) osd_setsound(NESmachine->apu->process);
      build_address_handlers(NESmachine);
      nes_setcontext(NESmachine);
      nes_reset();

      goto inscart_success;

inscart_fail:
      if (DEBUG) {
        Serial.println("Insert Cartridge Fail!");
        tft.println("Insert Cartridge Fail!");
      }
      while (1) {} //FREEZE

inscart_success:
      if (DEBUG) {
        Serial.println("Insert Cartridge OK.");
        tft.println("Insert Cartridge OK.");
      }

      MEMORY_STATUS();

      
      //START!
      while (NES_POWER == 1) { //NES EMULATION LOOP
        tickcnt = millis();

        nes_renderframe(true);
        /*#ifdef BLUETOOTH_ENABLED
              hid_update();
              PS4_JOY();
          #endif      */

        tickcnt = millis() - tickcnt; 
        if (tickcnt>0 && tickcnt < 16) vTaskDelay(16-tickcnt); //delay before next frame          
      }
      delay(1000);
      osd_stopsound(); ///must be delayed because crash...
      if (rominfo->sram!=NULL) free(rominfo->sram); ///free SRAM

      MEMORY_STATUS();
      NES_POWER = 1;
//--------------------------------------------------------------------------------
      break;
    case 2:
      MEMORY_STATUS();
      Serial.println("Starting Player application.");

      screenmemory_fillscreen(63); //black color

      sprintf(MAINPATH, "/AUDIO/");


      //malloc FILENAME array
      for (uint16_t tmp = 0; tmp < MAXFILES; tmp++) {
        filename[tmp] = (char*)malloc(MAXFILENAME_LENGTH);
      }
      audio.m_outBuff = (int16_t*)malloc(2048 * 2  * 2); //malloc 16bit * 2*2048
      
      audio.setPinout(I2S_BCLK, I2S_LRC, I2S_DOUT);
      audio.setVolume(VOLUME); // 0...21

      while (!EXIT) {
        ///if (JOY_SHARE == 1 && JOY_OPTIONS == 1) EXIT=true;
        //................................................................................
        Browse(MAINPATH);

        if (EXIT) break;

        delay(300);

        Serial.println(MAINPATH);
        Serial.print(PLAYINGFILE + 1);
        Serial.print('/');
        Serial.println(TOTALFILES);
        Serial.println(MAINPATH);

        audio.connecttoFS(SD, MAINPATH);

        screenmemory_fillscreen(63); //black color
        set_font_XY(16, 12 );
        sprintf(textbuf, "%d/%d", PLAYINGFILE + 1, TOTALFILES);
        draw_string(textbuf, 48);

        ///memset(textbuf, 0, 64);
        set_font_XY(16, 240 - 32);
        draw_string(TRACKNAME, 48);

        set_font_XY(16, 12 + 16);
        sprintf(textbuf, "VOL:%d%% %dHz %dbit %dCH", VOLUME * 100 / 22, audio.getSampleRate(), audio.getBitsPerSample(), audio.getChannels());
        draw_string(textbuf, 48);

        uint32_t prevtime = millis();

        PLAYING = true;
        PAUSED = false;

        while (PLAYING) {
          audio.loop();

          ///if (PLAYING) visualyze(); //visualyze when playing...
          xQueueSend(vidQueue, &SCREENMEMORY, 0); //refresh LCD
          vPortYield(); ///

          uint16_t h = 0; uint8_t m = 0; uint8_t s = 0;
          secondsToHMS( audio.getAudioCurrentTime(), h, m, s );
          set_font_XY(240 - 160, 12 );
          sprintf(textbuf, "%02d:%02d:%02d / ", h, m, s);
          draw_string(textbuf, 48);
          secondsToHMS( audio.getAudioFileDuration(), h, m, s );
          sprintf(textbuf, "%02d:%02d:%02d", h, m, s);
          draw_string(textbuf, 48);

          //PAUSE
          if ((JOY_OPTIONS == 0 && JOY_SHARE == 1) || digitalRead(PIN_A) == 1) {
            audio.pauseResume();            
            if (PAUSED == false) PAUSED = true;
            else PAUSED = false;
            delay(200);
          }

          //VOLUME+
          if ((digitalRead(PIN_UP) == 1 || JOY_UP == 1) && prevtime + 200 < millis()) {
            if (VOLUME < 22) VOLUME++;
            audio.setVolume(VOLUME); // 0...21
            set_font_XY(16, 12 + 16);
            sprintf(textbuf, "VOL:%d%% %dHz %dbit %dCH", VOLUME * 100 / 22, audio.getSampleRate(), audio.getBitsPerSample(), audio.getChannels());
            draw_string(textbuf, 48);
            ///delay(200);
            prevtime = millis();

            JOY_UP = 0;
          }

          //VOLUME-
          if ((digitalRead(PIN_DOWN) == 1 || JOY_DOWN == 1) && prevtime + 200 < millis()) {
            if (VOLUME > 0) VOLUME--;
            audio.setVolume(VOLUME); // 0...21
            set_font_XY(16, 12 + 16);
            sprintf(textbuf, "VOL:%d%% %dHz %dbit %dCH", VOLUME * 100 / 22, audio.getSampleRate(), audio.getBitsPerSample(), audio.getChannels());
            draw_string(textbuf, 48);
            ///delay(200);
            prevtime = millis();

            JOY_DOWN = 0;
          }

          //PLAY NEXT FILE AFTER END
          if (PLAYINGFILE < TOTALFILES - 1 && !audio.isRunning() && PAUSED == false) {
            if (PLAYINGFILE < TOTALFILES - 1) PLAYINGFILE++;
            PREVNEXT(MAINPATH, PLAYINGFILE);
            if (DEBUG) {
               Serial.print(PLAYINGFILE + 1);
               Serial.print('/');
               Serial.println(TOTALFILES);
               Serial.println(MAINPATH);
            }
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

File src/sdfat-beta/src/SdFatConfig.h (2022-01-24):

/**
 * Copyright (c) 2011-2019 Bill Greiman
 * This file is part of the SdFat library for SD memory cards.
 *
 * MIT License
 *
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
 * THE SOFTWARE IS PROVIDED "AS IS", WITHOUT WARRANTY OF ANY KIND, EXPRESS
 * OR IMPLIED, INCLUDING BUT NOT LIMITED TO THE WARRANTIES OF MERCHANTABILITY,
 * FITNESS FOR A PARTICULAR PURPOSE AND NONINFRINGEMENT. IN NO EVENT SHALL THE
 * AUTHORS OR COPYRIGHT HOLDERS BE LIABLE FOR ANY CLAIM, DAMAGES OR OTHER
 * LIABILITY, WHETHER IN AN ACTION OF CONTRACT, TORT OR OTHERWISE, ARISING
 * FROM, OUT OF OR IN CONNECTION WITH THE SOFTWARE OR THE USE OR OTHER
 * DEALINGS IN THE SOFTWARE.
 */
/**
 * \file
 * \brief configuration definitions
 */
#ifndef SdFatConfig_h
#define SdFatConfig_h
#include <stdint.h>
#ifdef __AVR__
#include <avr/io.h>
#endif  // __AVR__
/** For Debug - must be one */
#define ENABLE_ARDUINO_FEATURES 1
/** For Debug - must be one */
#define ENABLE_ARDUINO_SERIAL 1
/** For Debug - must be one */
#define ENABLE_ARDUINO_STRING 1
//------------------------------------------------------------------------------
/** Set USE_BLOCK_DEVICE_INTERFACE nonzero to use generic block device */
#define USE_BLOCK_DEVICE_INTERFACE 0
//------------------------------------------------------------------------------
#if ENABLE_ARDUINO_FEATURES
#include "Arduino.h"
#ifdef PLATFORM_ID
// Only defined if a Particle device.
#include "application.h"
#endif  // PLATFORM_ID
#endif  // ENABLE_ARDUINO_FEATURES
//------------------------------------------------------------------------------
/**
 * Set INCLUDE_SDIOS nonzero to include sdios.h in SdFat.h.
 * sdios.h provides C++ style IO Streams.
 */
#define INCLUDE_SDIOS 0
//------------------------------------------------------------------------------
/**
 * Set USE_FAT_FILE_FLAG_CONTIGUOUS nonzero to optimize access to 
 * contiguous files.
 */
#define USE_FAT_FILE_FLAG_CONTIGUOUS 1
//------------------------------------------------------------------------------
/**
 * File types for SdFat, File, SdFile, SdBaseFile, fstream,
 * ifstream, and ofstream.
 *
 * Set SDFAT_FILE_TYPE to:
 *
 * 1 for FAT16/FAT32, 2 for exFAT, 3 for FAT16/FAT32 and exFAT.
 */
#if defined(__AVR__) && FLASHEND < 0X8000
// 32K AVR boards.
#define SDFAT_FILE_TYPE 1
#else  // defined(__AVR__) && FLASHEND < 0X8000
// All other boards.
#define SDFAT_FILE_TYPE 1
#endif  // defined(__AVR__) && FLASHEND < 0X8000
//------------------------------------------------------------------------------
/**
 * Set ENABLE_DEDICATED_SPI to enable dedicated use of the SPI bus.
 * Selecting dedicated SPI in SdSpiConfig() will produce better
 * performance by using very large multi-block transfers to and
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
